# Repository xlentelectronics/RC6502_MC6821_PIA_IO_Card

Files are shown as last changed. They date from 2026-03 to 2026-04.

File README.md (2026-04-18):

# RC6502 MC6821 PIA IO Card

To provide I/O capabilities with the RC6502, an I/O card with the MC6821 PIA has been developed. To connect the card to the RC6502, simply insert it into the backplane. You can place the card in the desired address range using jumper J4. The included software samples use the base address $C000. The hardware and software have been developed under an open license.

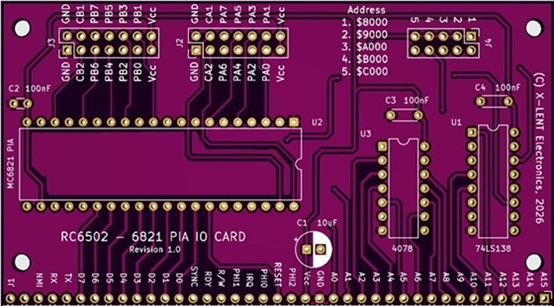
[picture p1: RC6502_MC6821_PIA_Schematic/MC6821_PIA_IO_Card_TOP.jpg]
Build MC6821 PIA IO Card

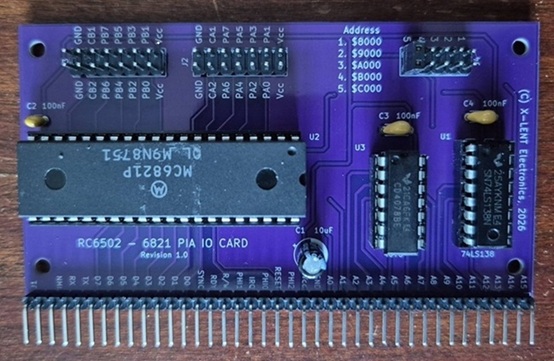
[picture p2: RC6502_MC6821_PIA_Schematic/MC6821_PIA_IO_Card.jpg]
Build MC6821 PIA IO Card


# Software Examples
In the Software Example folder are some examples how to use the MC6821 PIA IO Card. The examples are created for Krusader v1.3 and for MBASIC.

## Krusader assembler Example
In the Krusader Assembler folder the example MC6821_PingPong_Light_Speedmeter_Color.asm can be found.  This is a fully compatible Krusader v1.3 program. The program lets 8 LEDS running in a pingpong way. The speed can be controlled via the + and - of the numeric keypad of the keyboard.

The following hardware connection must be made to PORTA and PORTB. PORTA is connected to 8 LEDs. The anode of the LEDs is connected with a 1 kΩ resistor between Vcc and the corresponding pins PA0 through PA7. The .asm file can be loaded directly into Krusader v1.3. Make sure you have opened Krusader in edit mode (000) before loading the .asm file. If you use TeraTerm, you load the .asm via _Send file ..._ After successful load, assembler the file and run it via R $0300 (I assume you know how Krusader v1.3 works)

There is also as example the MC6821_PingPong_Light_Speedmeter_Color.woz. This file is the WoZ monitor compatible file. You can load the .woz file from the Woz Monitor in the same way by using _Send file ..._  

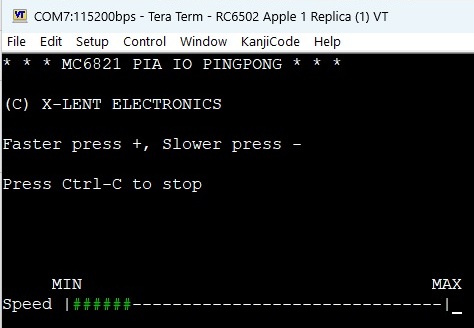
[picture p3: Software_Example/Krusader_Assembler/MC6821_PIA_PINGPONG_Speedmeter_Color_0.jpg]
PINGPONG Running Light Speedmeter at start

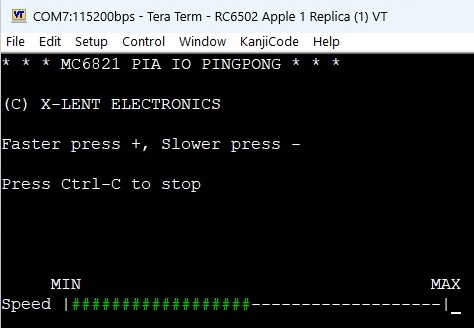
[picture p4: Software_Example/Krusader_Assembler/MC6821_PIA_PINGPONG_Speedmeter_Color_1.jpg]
Speedmeter Green

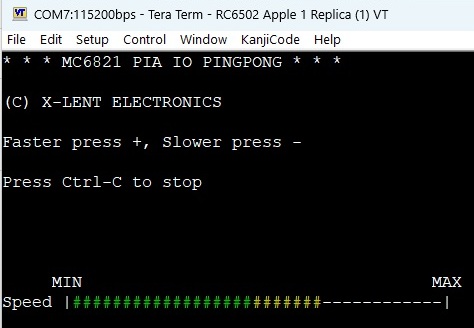
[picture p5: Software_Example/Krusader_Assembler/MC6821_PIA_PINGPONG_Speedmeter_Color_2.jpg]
Speedmeter Yellow Speedmeter Green-Yellow

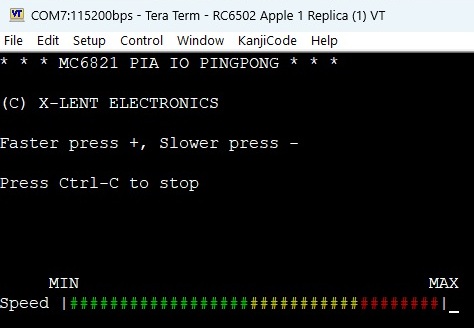
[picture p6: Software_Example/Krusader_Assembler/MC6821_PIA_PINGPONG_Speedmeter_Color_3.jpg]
Speedmeter Red Speedmeter Green-Yellow-Red
 

## MBASIC Examples
In the MBASIC folder there are 2 MBASIC examples, MBasic_MC6821_PIA_IO_RunningLight_PortA.bas and MBasic_MC6821_PIA_IO_RunningLight_Speed.bas.

Both MBASIC examples uses the same LED hardware connections as mentioned for the PINGPONG Running Light. An additional piece of hardware is required for the MBasic_MC6821_PIA_IO_RunningLight_Speed.bas.
Connect a push button via 10K resistor to Vcc and the other lead of the push button to GND. Connect PORTB PB7 to the 10K resistor. When you push the button, PB7 will go low.

Start MBASIC and load the .bas file via _Send file ..._ and type RUN to execute the program.

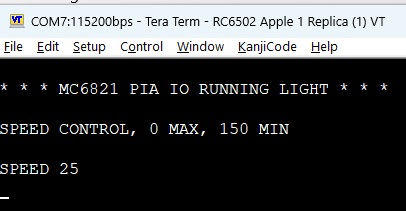
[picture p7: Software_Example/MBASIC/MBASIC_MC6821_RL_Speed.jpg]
MBASIC


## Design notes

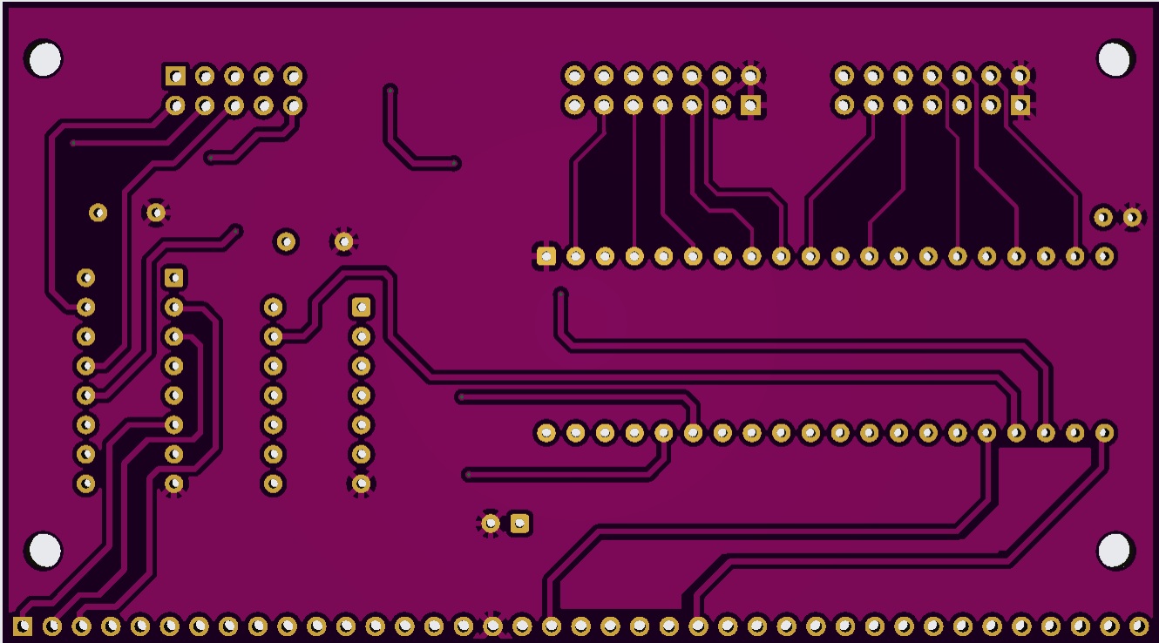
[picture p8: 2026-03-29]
RC6502_MC6821_PIA_Schematic/MC6821_PIA_IO_Card_BOTTOM.jpg

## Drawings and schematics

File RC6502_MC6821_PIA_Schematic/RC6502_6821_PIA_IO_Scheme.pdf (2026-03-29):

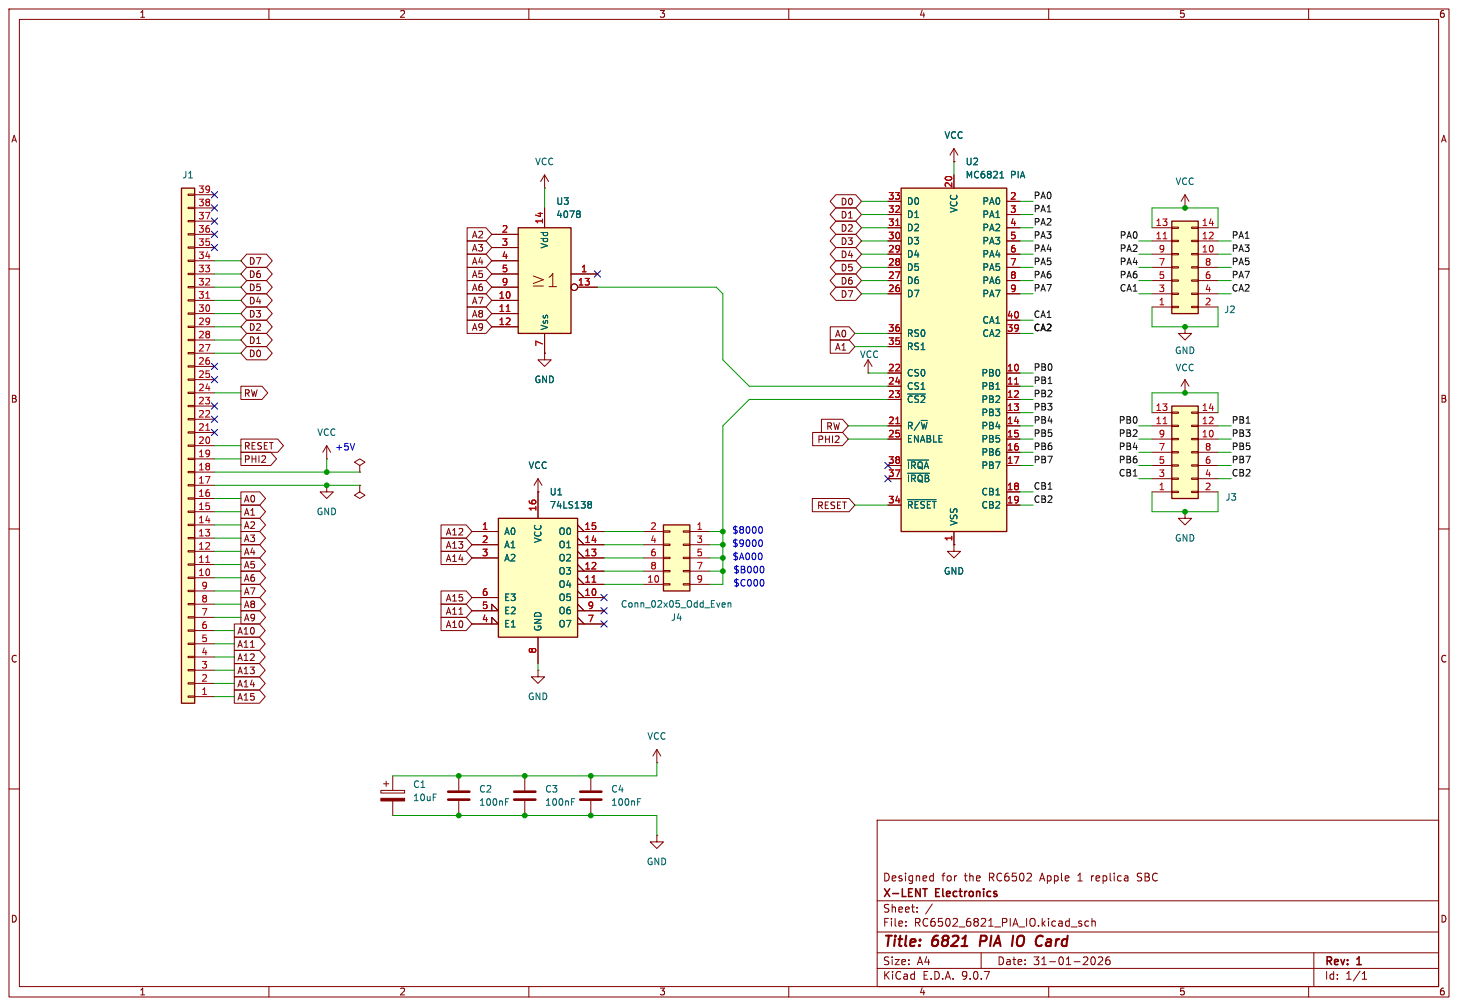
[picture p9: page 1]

4078 Vdd 14 Vss 7 23459
VCC þÿ"e1 Vdd 14 Vss 7 23459

Id: 1/1 Title: 6821 PIA IO Card

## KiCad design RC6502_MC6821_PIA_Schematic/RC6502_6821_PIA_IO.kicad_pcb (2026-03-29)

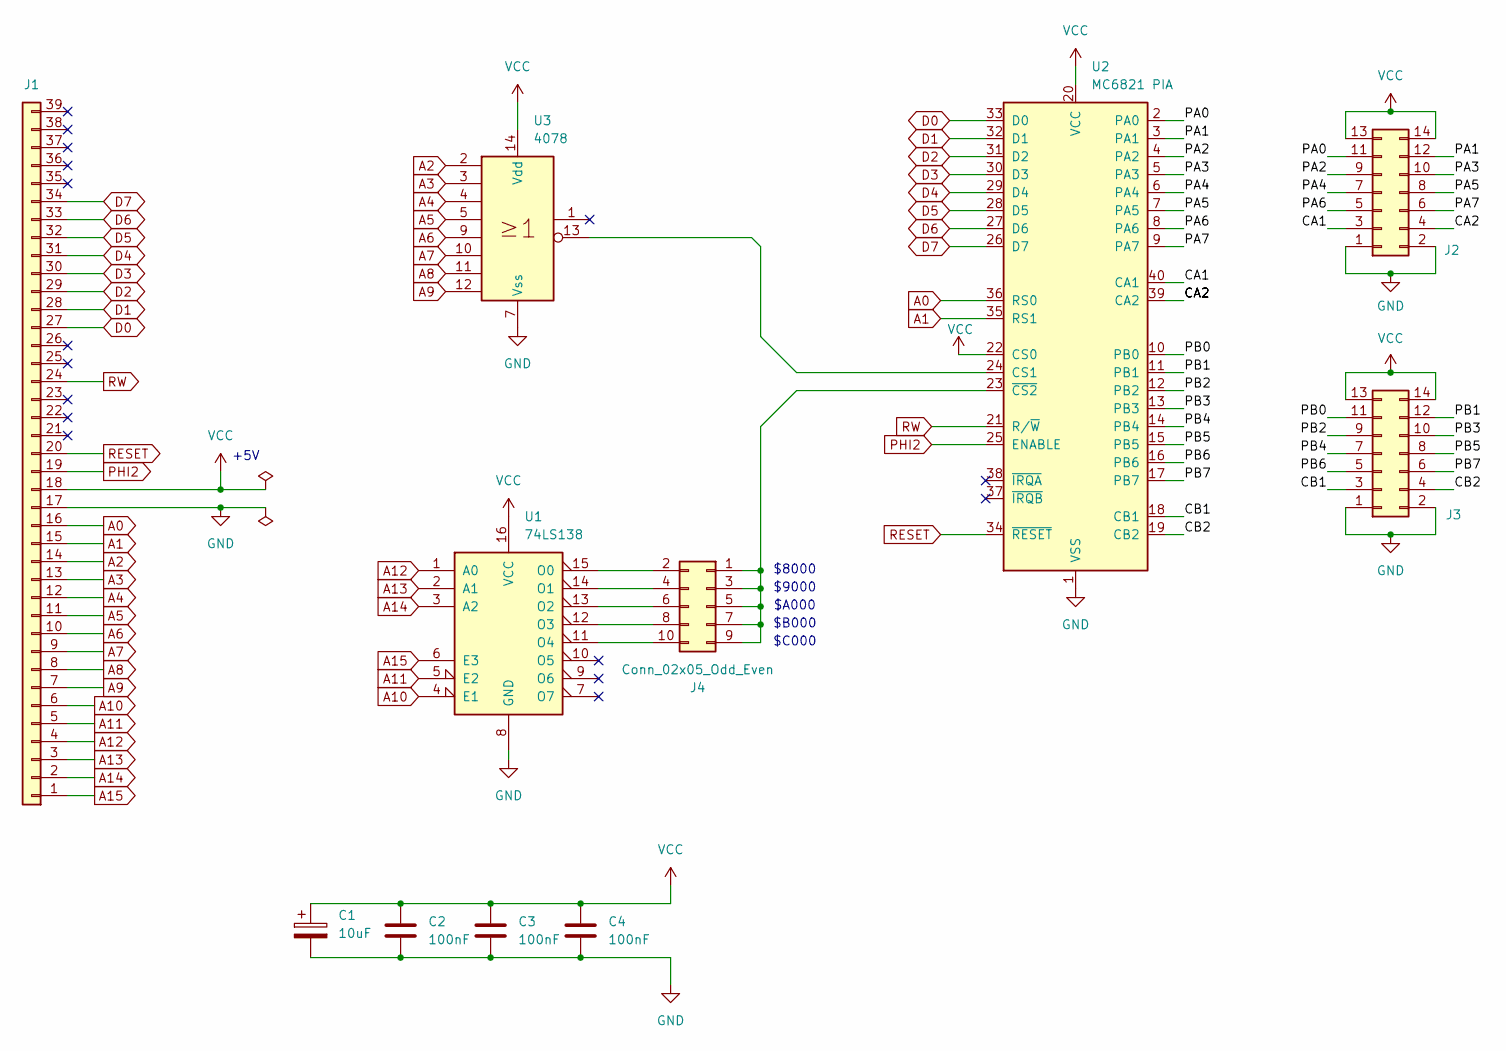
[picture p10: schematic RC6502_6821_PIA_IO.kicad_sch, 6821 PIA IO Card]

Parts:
C1: 10uF; CP_Radial_D6.3mm_P2.50mm
C2: 100nF; C_Disc_D3.0mm_W1.6mm_P2.50mm
C3, C4: 100nF; C_Disc_D4.3mm_W1.9mm_P5.00mm
J1: Conn_01x39; PinHeader_1x39_P2.54mm_Horizontal
J2, J3: Conn_02x07_Odd_Even; PinHeader_2x07_P2.54mm_Vertical
J4: Conn_02x05_Odd_Even; PinHeader_2x05_P2.54mm_Vertical
U1: 74LS138; DIP-16_W7.62mm
U2: MC6821 PIA; DIP-40_W15.24mm
U3: 4078; DIP-14_W7.62mm

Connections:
/CA1: J2.3, U2.40 (CA1)
/CA2: J2.4, U2.39 (CA2)
/CB1: J3.3, U2.18 (CB1)
/CB2: J3.4, U2.19 (CB2)
/PA0: J2.11, U2.2 (PA0)
/PA1: J2.12, U2.3 (PA1)
/PA2: J2.9, U2.4 (PA2)
/PA3: J2.10, U2.5 (PA3)
/PA4: J2.7, U2.6 (PA4)
/PA5: J2.8, U2.7 (PA5)
/PA6: J2.5, U2.8 (PA6)
/PA7: J2.6, U2.9 (PA7)
/PB0: J3.11, U2.10 (PB0)
/PB1: J3.12, U2.11 (PB1)
/PB2: J3.9, U2.12 (PB2)
/PB3: J3.10, U2.13 (PB3)
/PB4: J3.7, U2.14 (PB4)
/PB5: J3.8, U2.15 (PB5)
/PB6: J3.5, U2.16 (PB6)
/PB7: J3.6, U2.17 (PB7)
A0: J1.16, U2.36 (RS0)
A1: J1.15, U2.35 (RS1)
A2: J1.14, U3.2
A3: J1.13, U3.3
A4: J1.12, U3.4
A5: J1.11, U3.5
A6: J1.10, U3.9
A7: J1.9, U3.10
A8: J1.8, U3.11
A9: J1.7, U3.12
A10: J1.6, U1.4 (E1)
A11: J1.5, U1.5 (E2)
A12: J1.4, U1.1 (A0)
A13: J1.3, U1.2 (A1)
A14: J1.2, U1.3 (A2)
A15: J1.1, U1.6 (E3)
D0: J1.27, U2.33 (D0)
D1: J1.28, U2.32 (D1)
D2: J1.29, U2.31 (D2)
D3: J1.30, U2.30 (D3)
D4: J1.31, U2.29 (D4)
D5: J1.32, U2.28 (D5)
D6: J1.33, U2.27 (D6)
D7: J1.34, U2.26 (D7)
GND: C1.2, C2.2, C3.2, C4.2, J1.17, J2.1, J2.2, J3.1, J3.2, U1.8 (GND), U2.1 (VSS), U3.7 (Vss)
unnamed: J4.1, J4.3, J4.5, J4.7, J4.9, U2.23 (~CS2)
unnamed: J4.2, U1.15 (O0)
unnamed: J4.4, U1.14 (O1)
unnamed: J4.6, U1.13 (O2)
unnamed: J4.8, U1.12 (O3)
unnamed: J4.10, U1.11 (O4)
unnamed: U2.24 (CS1), U3.13
PHI2: J1.19, U2.25 (ENABLE)
RESET: J1.20, U2.34 (~RESET)
RW: J1.24, U2.21 (R/~W)
VCC: C1.1, C2.1, C3.1, C4.1, J1.18, J2.13, J2.14, J3.13, J3.14, U1.16 (VCC), U2.20 (VCC), U2.22 (CS0), U3.14 (Vdd)

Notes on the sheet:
$9000
$B000
$C000
$8000
$A000
+5V

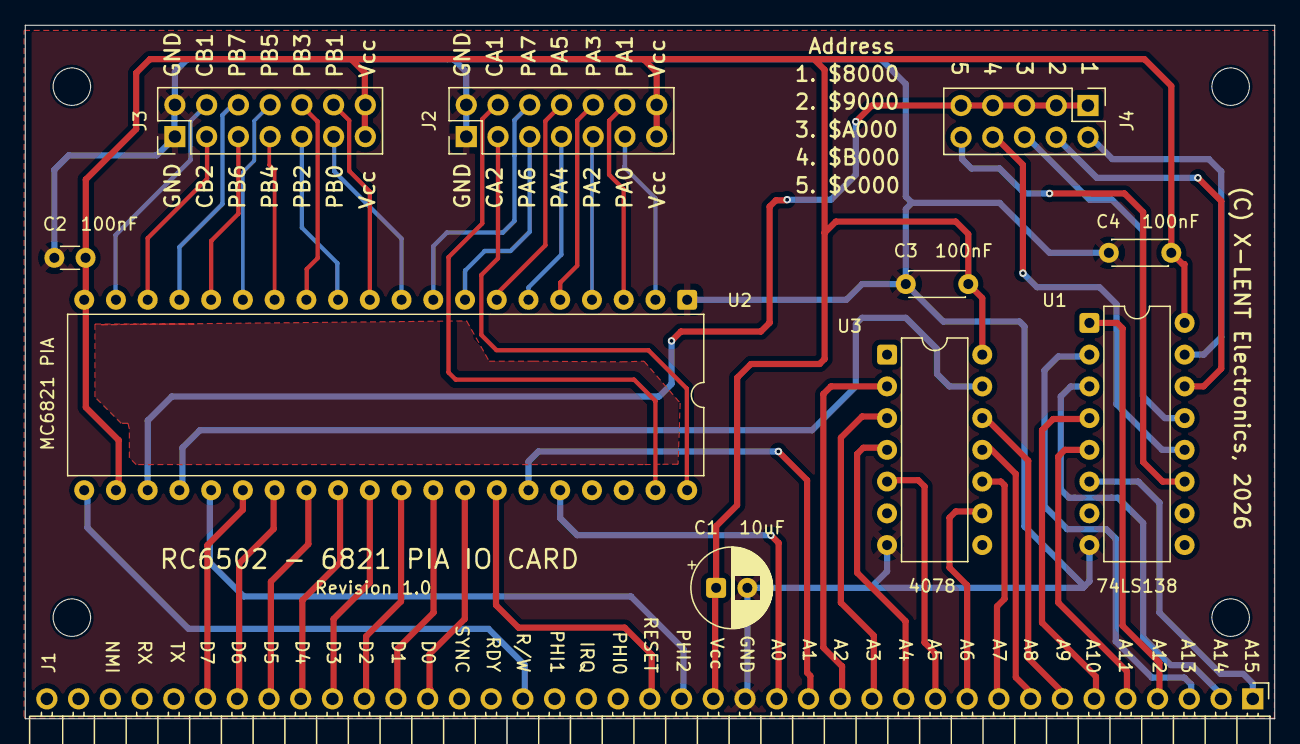
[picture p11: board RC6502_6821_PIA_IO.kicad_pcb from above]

Board: 2 copper layers, 100.0 x 55.5 mm, 11 parts (0 on the bottom side), 56 nets.

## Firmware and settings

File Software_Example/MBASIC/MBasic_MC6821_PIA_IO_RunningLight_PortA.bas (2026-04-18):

1 PRINT CHR$(27);"[2J"; : PRINT CHR$(27);"[1;1H"
10 PRINT "* * * MC6821 PIA IO RUNNING LIGHT * * *" : PRINT
15 PRINT "    * * * X-LENT ELECTRONICS * * *" : PRINT
20 INPUT "ENTER MC6821 PIA IO BASE ADDRESS $<ADDRESS>:"; BA$
25 PRINT "BASE ADDRES IS: ";BA$
30 IF BA$ = "$C000" THEN BA = 49152
35 IF BA$ = "$B000" THEN BA = 45056
40 IF BA$ = "$A000" THEN BA = 40960
45 IF BA$ = "$9000" THEN BA = 36864
50 IF BA$ = "$8000" THEN BA = 32768
55 REM -- INITIALIZE MC6521 PIA --
60 POKE BA+1, 0		: REM CRA address 0xC001. Select DDRA
70 POKE BA, 255	: REM DDRA address 0xC000. Set DDRA as OUTPUT 
80 POKE BA+1, 4		: REM Select DRA register
90 POKE BA, 255	: REM Set DRA OUTPUTS to 1, LEDS are OFF
100 POKE BA+3, 0		: REM CRB ADDRESS 0xC003. Select DDRB
110 POKE BA+2, 255	: REM DDRB ADDRES 0xC002. Set DDRB as OUTPUT	
120 POKE BA+3, 4		: REM Select DRB register
130 POKE BA+2, 255	: REM Set DRB OUTPUTS to 1, LEDS are OFF	
140 REM -- START RUNNINGLIGHT --
150 REM -- LEFT TO RIGHT -- 
160 FOR I = 0 TO 7
170 X = (255 - INT(2^I))
180 POKE BA, X
190 GOSUB 300
200 NEXT I
210 REM -- RIGHT TO LEFT --
220 FOR I = 6 TO 1 STEP -1
230 X = (255 - INT(2^I))
240 POKE BA, X
250 GOSUB 300
260 NEXT I
270 GOTO 110
300 REM GOSUB -- DELAY --
310 FOR D = 1 TO 25
320 NEXT D
330 RETURN

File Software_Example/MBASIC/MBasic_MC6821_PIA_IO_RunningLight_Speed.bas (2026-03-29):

1 PRINT CHR$(27);"[2J"; : PRINT CHR$(27);"[1;1H"
5 PRINT "* * * MC6821 PIA IO RUNNING LIGHT * * *"
10 PRINT CHR$(27);"[3;1H" : PRINT "SPEED CONTROL, 0 MAX, 150 MIN"
15 REM -- INITIALIZE MC6521 PIA ---
20 POKE 49153,0		: REM CRA address 0xC001. Select DDRA
30 POKE 49152,255	: REM DDRA address 0xC000. Set DDRA as OUTPUT 
40 POKE 49153,4		: REM Select DRA register
50 POKE 49152,255	: REM Set DRA OUTPUTS to 1, LEDS are OFF
60 POKE 49155,0		: REM CRB ADDRESS 0xC003. Select DDRB
70 POKE 49154,127	: REM DDRB ADDRES 0xC002. Set DDRB PB0~PB6 OUTPUT, PB7 as INPUT	
80 POKE 49155,4		: REM Select DRB register
90 POKE 49154,127	: REM Set DRB PB0-PB6 OUTPUTS to 1, LEDS are OFF	
100 X = 0
110 REM -- START RUNNINGLIGHT ---
120 REM -- LEFT TO RIGHT --
130 FOR I = 0 TO 7
140 A = (255 - INT(2^I))
150 POKE 49152,A
160 GOSUB 400
170 NEXT I
180 REM -- RIGHT TO LEFT --
190 FOR I = 6 TO 1 STEP -1
200 A = (255 - INT(2^I))
210 POKE 49152,A
220 GOSUB 400
230 NEXT I
240 GOTO 110
400 REM GOSUB -- DELAY --
405 Z = PEEK(49154)
410 IF (Z AND 128) =< 127 THEN X = X + 5
420 IF X > 150 THEN X = 0 
425 PRINT CHR$(27);"[5;1H" : PRINT "SPEED"; X ; "   "
430 FOR D = 0 TO X : REM DELAY
440 NEXT D
450 RETURN
